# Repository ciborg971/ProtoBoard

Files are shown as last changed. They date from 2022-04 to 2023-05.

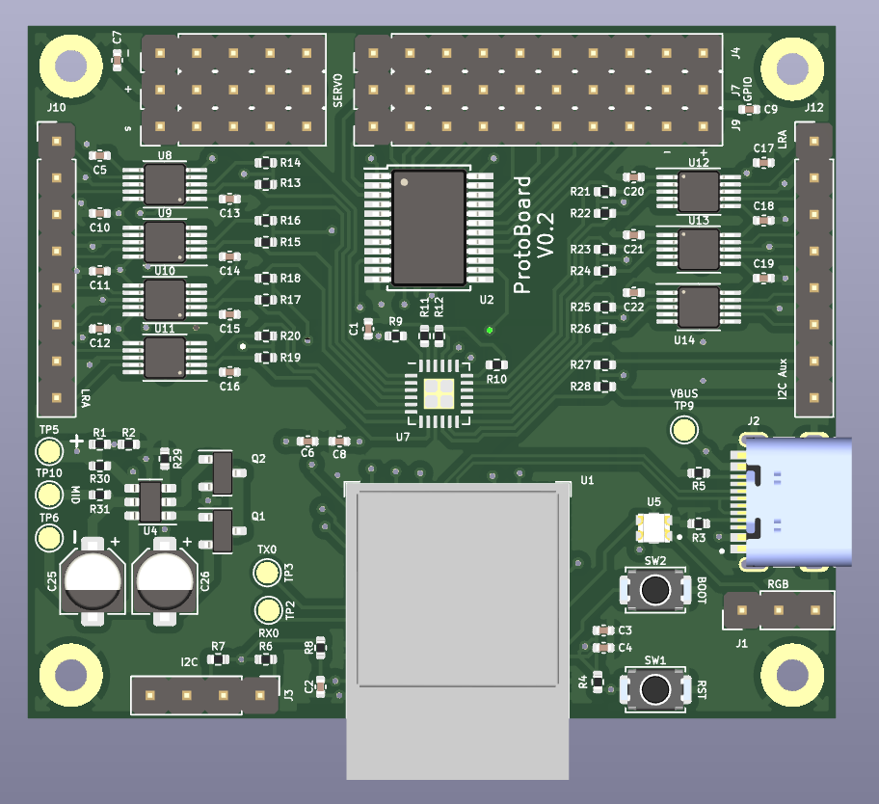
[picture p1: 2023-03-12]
media/3dTop.png

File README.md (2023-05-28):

# ProtoBoard V0.2

A small board (48 x 56 mm) for great gloves !

* Still a work in progress, current version does NOT work * 





# Features

## Pros :
- ESP32S3 dual core
- Small (48x56 mm)
- Power from 2S to 4S lipo (accept 6.5 volt up to 20 volt)
- Can use Wifi (doesnt use ADC2)
- 16 ADC input
- RGB Header
- 5V 5A for Servo for up to 5 Servo
- Support up to 7 LRA
- Battery protection (integrated BMS : overcharge, overdischarge and overcurrent protection)
- Battery level (via voltage divider)
- Cheap to build
- Use 2.54 mm header
- USB C for programming (The board CANNOT be powered via USB)

## Cons :
- Compoment on both side => more expensive to produce in small quantity in pcb fab (bottom side have easy to solder components)
- Doesnt charge the battery
- PCB is 4 layer (a bit more expensive than 2 layer PCB)

## Buy the PCB

*This design does NOT work right now, do NOT buy it unless you can debug it by yourself*
You can buy the board via PCBWay using the file ProtoBoard.kicad_pcb.zip and the BOM ProtoBoard.xlsx.

## TODO

- Add pinout

## Sponsors

This project is sponsored by PCBWay, thanks to them for their quality PCB + assembly !

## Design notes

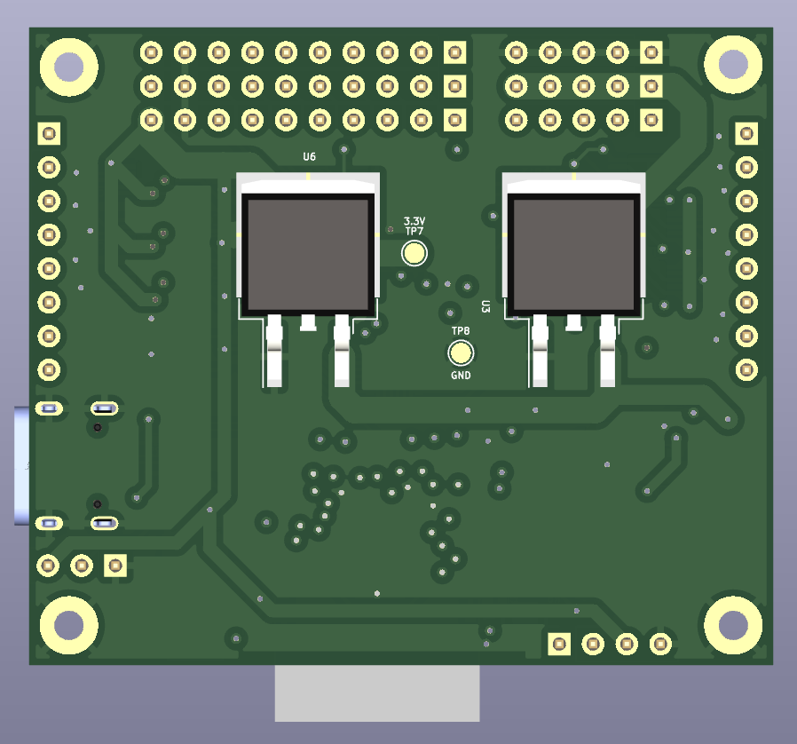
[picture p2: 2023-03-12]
media/3dBot.png

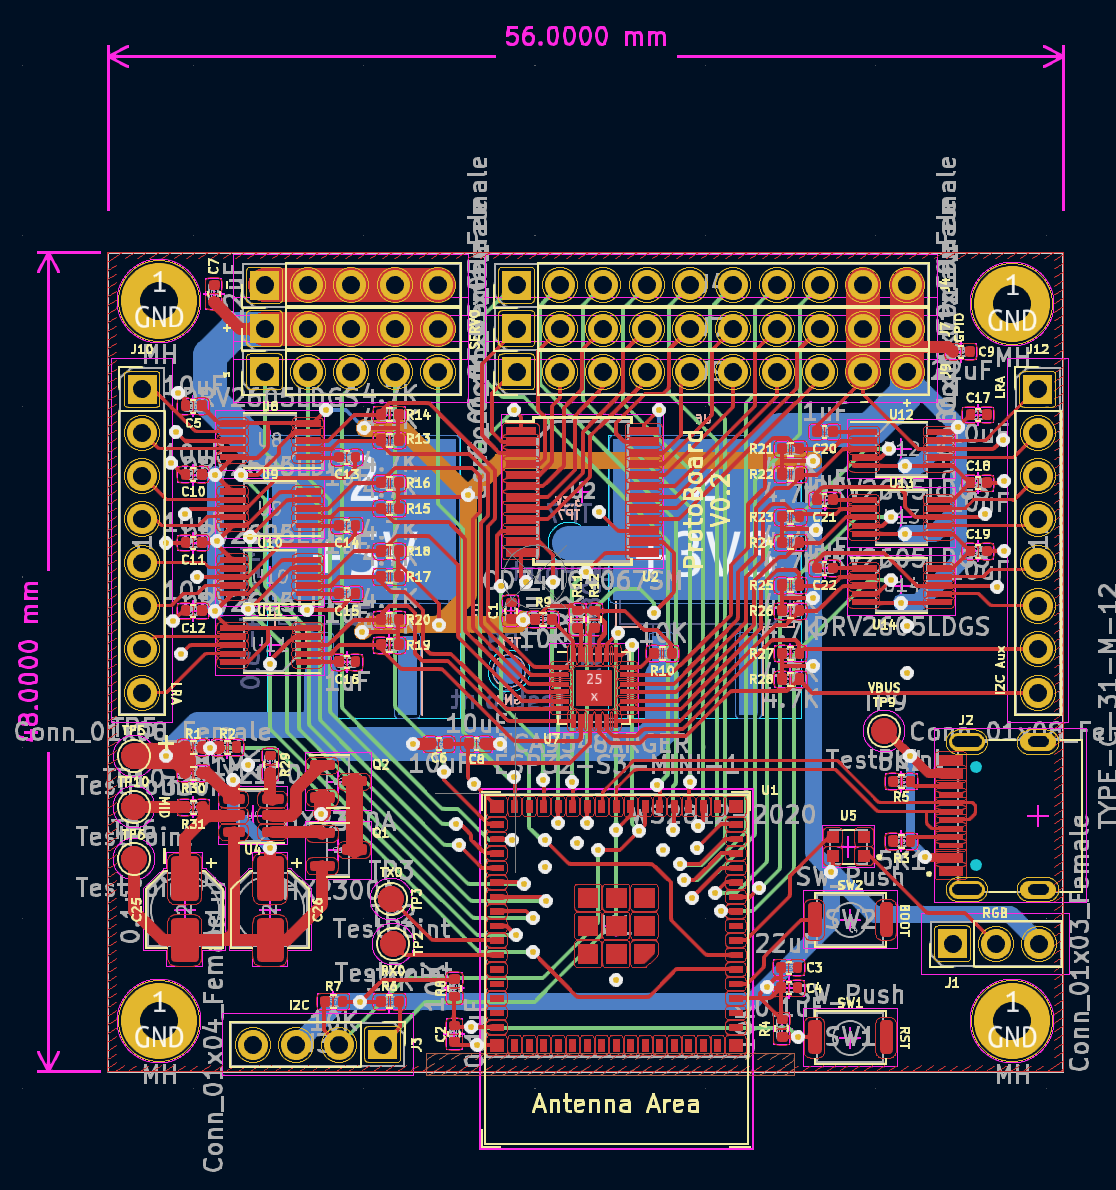
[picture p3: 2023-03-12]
media/Pcb.png

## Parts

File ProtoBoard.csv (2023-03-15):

Source: | C:\Users\termi\source\repos\ProtoBoard\ProtoBoard.kicad_sch
Date: | 15/03/2023 18:05:43
Tool: | Eeschema (6.0.11)
Generator: | C:\Program Files\KiCad\6.0\bin\scripting\plugins/bom_csv_grouped_by_value_with_fp.py
Component Count: | 96
Ref | Qnty | Value | Cmp name | Footprint | Description | Vendor
C1, C5, C6, C8, C10, C11, C12, C17, C18, C19, | 10 | 10uF | C | Capacitor_SMD:C_0402_1005Metric | Unpolarized capacitor
C2, C4, | 2 | 0.1uF | C | Capacitor_SMD:C_0402_1005Metric | Unpolarized capacitor
C3, C7, C9, | 3 | 22uF | C | Capacitor_SMD:C_0402_1005Metric | Unpolarized capacitor
C13, C14, C15, C16, C20, C21, C22, | 7 | 1uF | C | Capacitor_SMD:C_0402_1005Metric | Unpolarized capacitor
C25, C26, | 2 | 0.1uF | C_Polarized_Small | Capacitor_SMD:CP_Elec_4x5.4 | Polarized capacitor, small symbol
H1, H2, H3, H4, | 4 | MH | MountingHole_Pad | MountingHole:MountingHole_2.2mm_M2_Pad | Mounting Hole with connection
J1, | 1 | Conn_01x03_Female | Conn_01x03_Female | Connector_PinHeader_2.54mm:PinHeader_1x03_P2.54mm_Vertical | Generic connector, single row, 01x03, script generated (kicad-library-utils/schlib/autogen/connector/)
J2, | 1 | TYPE-C-31-M-12 | TYPE-C-31-M-12 | TYPE-C-31-M-12:HRO_TYPE-C-31-M-12
J3, | 1 | Conn_01x04_Female | Conn_01x04_Female | Connector_PinHeader_2.54mm:PinHeader_1x04_P2.54mm_Vertical | Generic connector, single row, 01x04, script generated (kicad-library-utils/schlib/autogen/connector/)
J4, J7, J9, | 3 | Conn_01x10_Female | Conn_01x10_Female | Connector_PinHeader_2.54mm:PinHeader_1x10_P2.54mm_Vertical | Generic connector, single row, 01x10, script generated (kicad-library-utils/schlib/autogen/connector/)
J5, J6, J8, | 3 | Conn_01x05_Female | Conn_01x05_Female | Connector_PinHeader_2.54mm:PinHeader_1x05_P2.54mm_Vertical | Generic connector, single row, 01x05, script generated (kicad-library-utils/schlib/autogen/connector/)
J10, J12, | 2 | Conn_01x08_Female | Conn_01x08_Female | Connector_PinHeader_2.54mm:PinHeader_1x08_P2.54mm_Vertical | Generic connector, single row, 01x08, script generated (kicad-library-utils/schlib/autogen/connector/)
Q1, Q2, | 2 | HX2300A | 2N7002E | Package_TO_SOT_SMD:SOT-23 | 0.24A Id, 60V Vds, N-Channel MOSFET, SOT-23
R1, | 1 | 5M | R | Resistor_SMD:R_0402_1005Metric | Resistor
R2, | 1 | 1M | R | Resistor_SMD:R_0402_1005Metric | Resistor
R3, R5, | 2 | 5K1 | R | Resistor_SMD:R_0402_1005Metric | Resistor
R4, R6, R7, R8, R9, R10, R11, R12, | 8 | 10K | R | Resistor_SMD:R_0402_1005Metric | Resistor
R13, R14, R15, R16, R17, R18, R19, R20, R21, R22, R23, R24, R25, R26, R27, R28, | 16 | 4.7K | R | Resistor_SMD:R_0402_1005Metric | Resistor
R29, | 1 | 2K | R | Resistor_SMD:R_0402_1005Metric | Resistor
R30, R31, | 2 | 330R | R | Resistor_SMD:R_0402_1005Metric | Resistor
SW1, SW2, | 2 | SW_Push | SW_Push | Button_Switch_SMD:SW_Push_SPST_NO_Alps_SKRK | Push button switch, generic, two pins
TP2, TP3, TP5, TP6, TP7, TP8, TP9, TP10, | 8 | TestPoint | TestPoint | TestPoint:TestPoint_Pad_D1.5mm | test point
U1, | 1 | ESP32-S3-MINI-1 | ESP32-S3-MINI-1 | Espressif:ESP32-S3-MINI-1 | Smallsized module supporting 2.4 GHz WiFi (802.11 b/g/n) and Bluetooth ® 5 (LE) Built around ESP32S3 series of SoCs, Xtensa ® dualcore 32bit LX7 microprocessor Flash up to 8 MB, optional 2 MB PSRAM in chip package 39 GPIOs, rich set of peripherals Onboard PCB antenna or external antenna connector
U2, | 1 | CD74HC4067SM | CD74HC4067SM | Package_SO:SSOP-24_5.3x8.2mm_P0.65mm | High-Speed CMOS Logic 16-Channel Analog Multiplexer/Demultiplexer, SSOP-24
U3, | 1 | LM1084-5.0 | LM1084-5.0 | Package_TO_SOT_SMD:TO-263-2 | 5A 27V Linear Regulator, Fixed Output 5.0V, TO-220/TO-263
U4, | 1 | HY2120 | HY2120 | Package_TO_SOT_SMD:SOT-23-6
U5, | 1 | WS2812-2020 | WS2812-2020 | WS2812-2020:LED_WS2812-2020
U6, | 1 | LM1084-3.3 | LM1084-3.3 | Package_TO_SOT_SMD:TO-263-2 | 5A 27V Linear Regulator, Fixed Output 3.3V, TO-220/TO-263
U7, | 1 | TCA9548ARGER | TCA9548ARGER | Package_DFN_QFN:Texas_RGE0024C_EP2.1x2.1mm | Low voltage 8-channel I2C switch with reset, QFN-24
U8, U9, U10, U11, U12, U13, U14, | 7 | DRV2605LDGS | DRV2605LDGS | Package_SO:VSSOP-10_3x3mm_P0.5mm | Haptic driver for LRAs and ERMs with effect library, 2-5.2V, VSSOP-10

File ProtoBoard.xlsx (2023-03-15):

Source: | ProtoBoard\ProtoBoard.kicad_sch
Component Count: | 77
Ref | Qnty | Value | Cmp name | Footprint | Description | Vendor | LCSC
C1, C5, C6, C8, C10, C11, C12, C17, C18, C19, | 10 | 10uF | C | Capacitor_SMD:C_0402_1005Metric | Unpolarized capacitor |  | C315248
C2, C4, | 2 | 0.1uF | C | Capacitor_SMD:C_0402_1005Metric | Unpolarized capacitor |  | C129131
C3, C7, C9, | 3 | 22uF | C | Capacitor_SMD:C_0402_1005Metric | Unpolarized capacitor |  | C415703
C13, C14, C15, C16, C20, C21, C22, | 7 | 1uF | C | Capacitor_SMD:C_0402_1005Metric | Unpolarized capacitor |  | C14445
C25, C26, | 2 | 0.1uF | C_Polarized_Small | Capacitor_SMD:CP_Elec_4x5.4 | Polarized capacitor, small symbol |  | C1525
J2, | 1 | TYPE-C-31-M-12 | TYPE-C-31-M-12 | TYPE-C-31-M-12:HRO_TYPE-C-31-M-12 |  |  | C165948
J5, J6, J8, | 3 | Conn_01x05_Female | Conn_01x05_Female | Connector_PinHeader_2.54mm:PinHeader_1x05_P2.54mm_Vertical | Generic connector, single row, 01x05, script generated (kicad-library-utils/schlib/autogen/connector/) |  | C492404
Q1, Q2, | 2 | HX2300A | 2N7002E | Package_TO_SOT_SMD:SOT-23 | 0.24A Id, 60V Vds, N-Channel MOSFET, SOT-23 |  | C296302
R1, | 1 | 5M | R | Resistor_SMD:R_0402_1005Metric | Resistor |  | C269650
R2, | 1 | 1M | R | Resistor_SMD:R_0402_1005Metric | Resistor |  | C138033
R3, R5, | 2 | 5K1 | R | Resistor_SMD:R_0402_1005Metric | Resistor |  | C25905
R4, R6, R7, R8, R9, R10, R11, R12, | 8 | 10K | R | Resistor_SMD:R_0402_1005Metric | Resistor |  | C60490
R13, R14, R15, R16, R17, R18, R19, R20, R21, R22, R23, R24, R25, R26, R27, R28, | 16 | 4.7K | R | Resistor_SMD:R_0402_1005Metric | Resistor |  | C105871
R29, | 1 | 2K | R | Resistor_SMD:R_0402_1005Metric | Resistor |  | C60488
R30, R31, | 2 | 330R | R | Resistor_SMD:R_0402_1005Metric | Resistor |  | C105875
SW1, SW2, | 2 | SW_Push | SW_Push | Button_Switch_SMD:SW_Push_SPST_NO_Alps_SKRK | Push button switch, generic, two pins |  | C115357
U1, | 1 | ESP32-S3-MINI-1 | ESP32-S3-MINI-1 | Espressif:ESP32-S3-MINI-1 | Smallsized module supporting 2.4 GHz WiFi (802.11 b/g/n) and Bluetooth ® 5 (LE) Built around ESP32S3 series of SoCs, Xtensa ® dualcore 32bit LX7 microprocessor Flash up to 8 MB, optional 2 MB PSRAM in chip package 39 GPIOs, rich set of peripherals Onboard PCB antenna or external antenna connector |  | C2913206
U2, | 1 | CD74HC4067SM | CD74HC4067SM | Package_SO:SSOP-24_5.3x8.2mm_P0.65mm | High-Speed CMOS Logic 16-Channel Analog Multiplexer/Demultiplexer, SSOP-24 |  | C98457
U3, | 1 | LM1084-5.0 | LM1084-5.0 | Package_TO_SOT_SMD:TO-263-2 | 5A 27V Linear Regulator, Fixed Output 5.0V, TO-220/TO-263 |  | C259973
U4, | 1 | HY2120 | HY2120-CB | Package_TO_SOT_SMD:SOT-23-6 |  |  | C116509
U5, | 1 | WS2812-2020 | WS2812B-2020 | WS2812-2020:LED_WS2812-2020 |  |  | C965555
U6, | 1 | LM1084-3.3 | LM1084-3.3 | Package_TO_SOT_SMD:TO-263-2 | 5A 27V Linear Regulator, Fixed Output 3.3V, TO-220/TO-263 |  | C259972
U7, | 1 | TCA9548ARGER | TCA9548ARGER | Package_DFN_QFN:Texas_RGE0024C_EP2.1x2.1mm | Low voltage 8-channel I2C switch with reset, QFN-24 |  | C555456
U8, U9, U10, U11, U12, U13, U14, | 7 | DRV2605LDGS | DRV2605LDGS | Package_SO:VSSOP-10_3x3mm_P0.5mm | Haptic driver for LRAs and ERMs with effect library, 2-5.2V, VSSOP-10 |  | C527464

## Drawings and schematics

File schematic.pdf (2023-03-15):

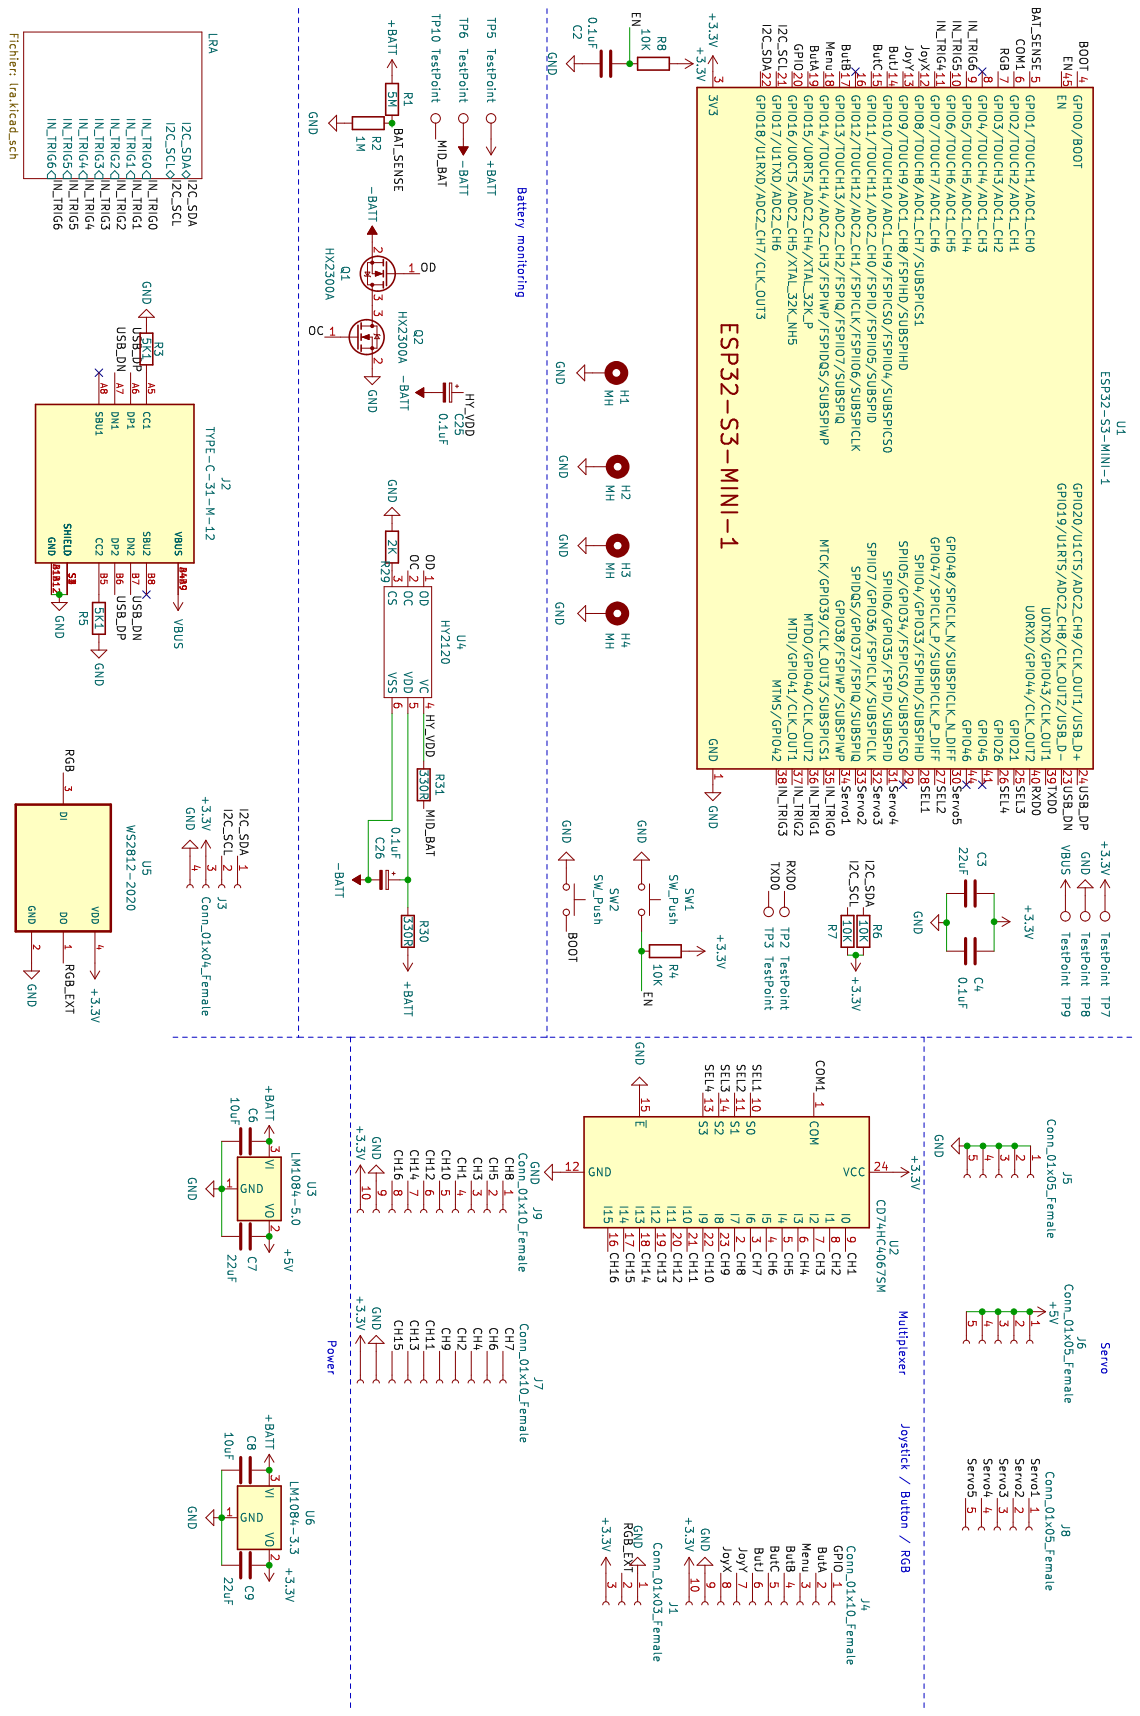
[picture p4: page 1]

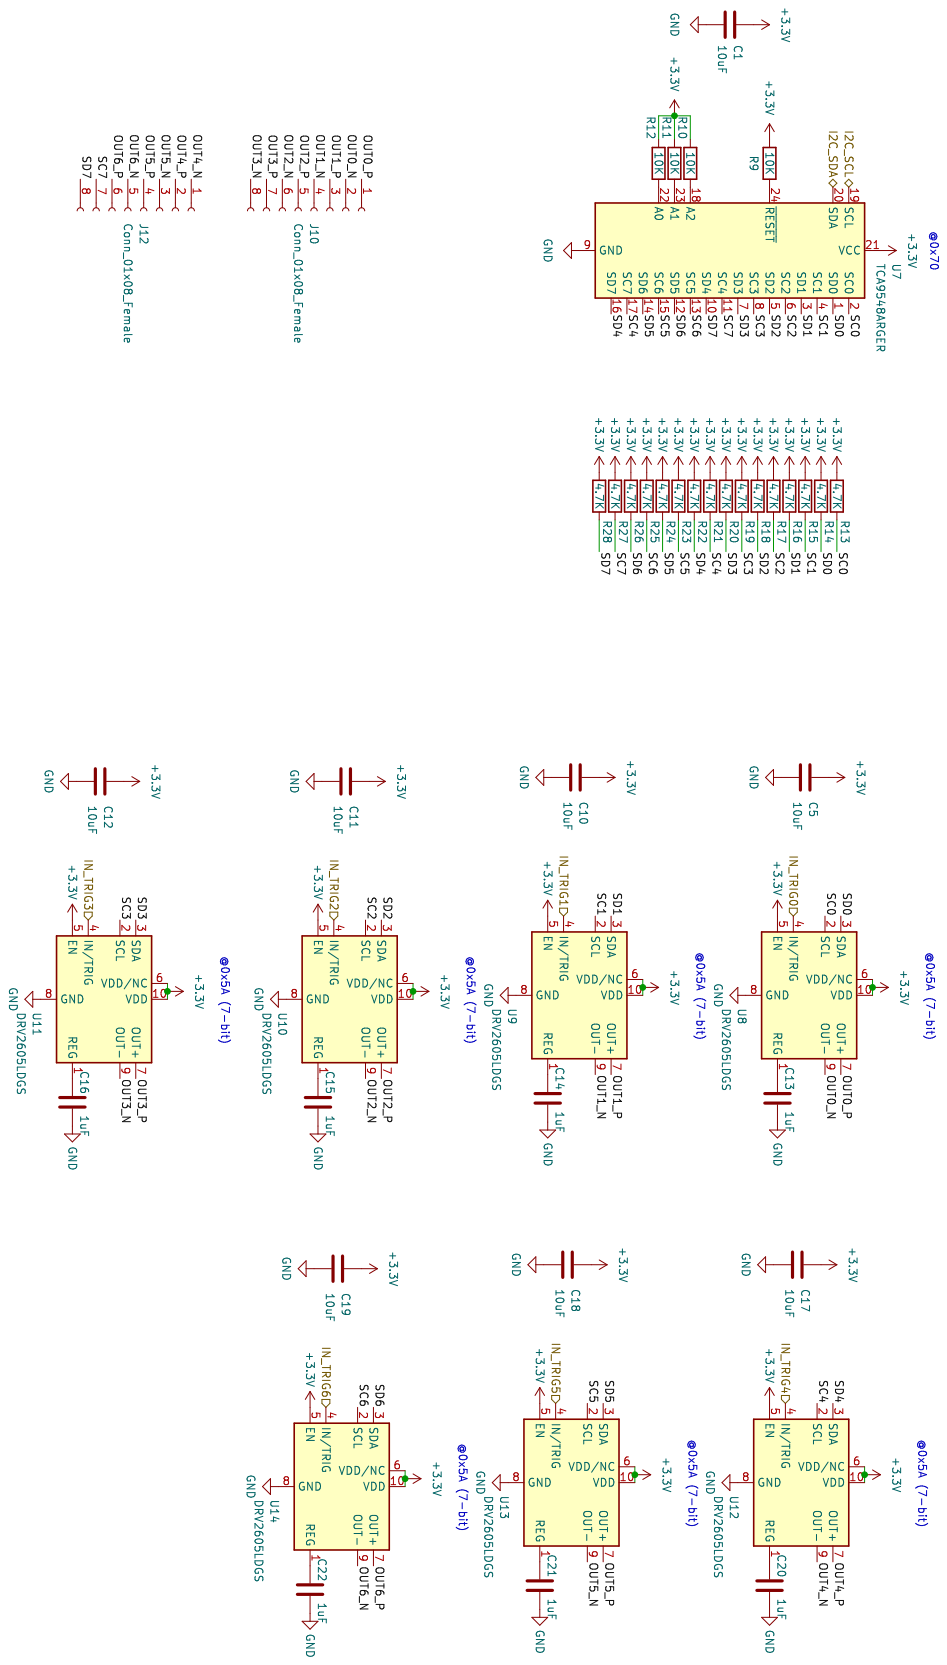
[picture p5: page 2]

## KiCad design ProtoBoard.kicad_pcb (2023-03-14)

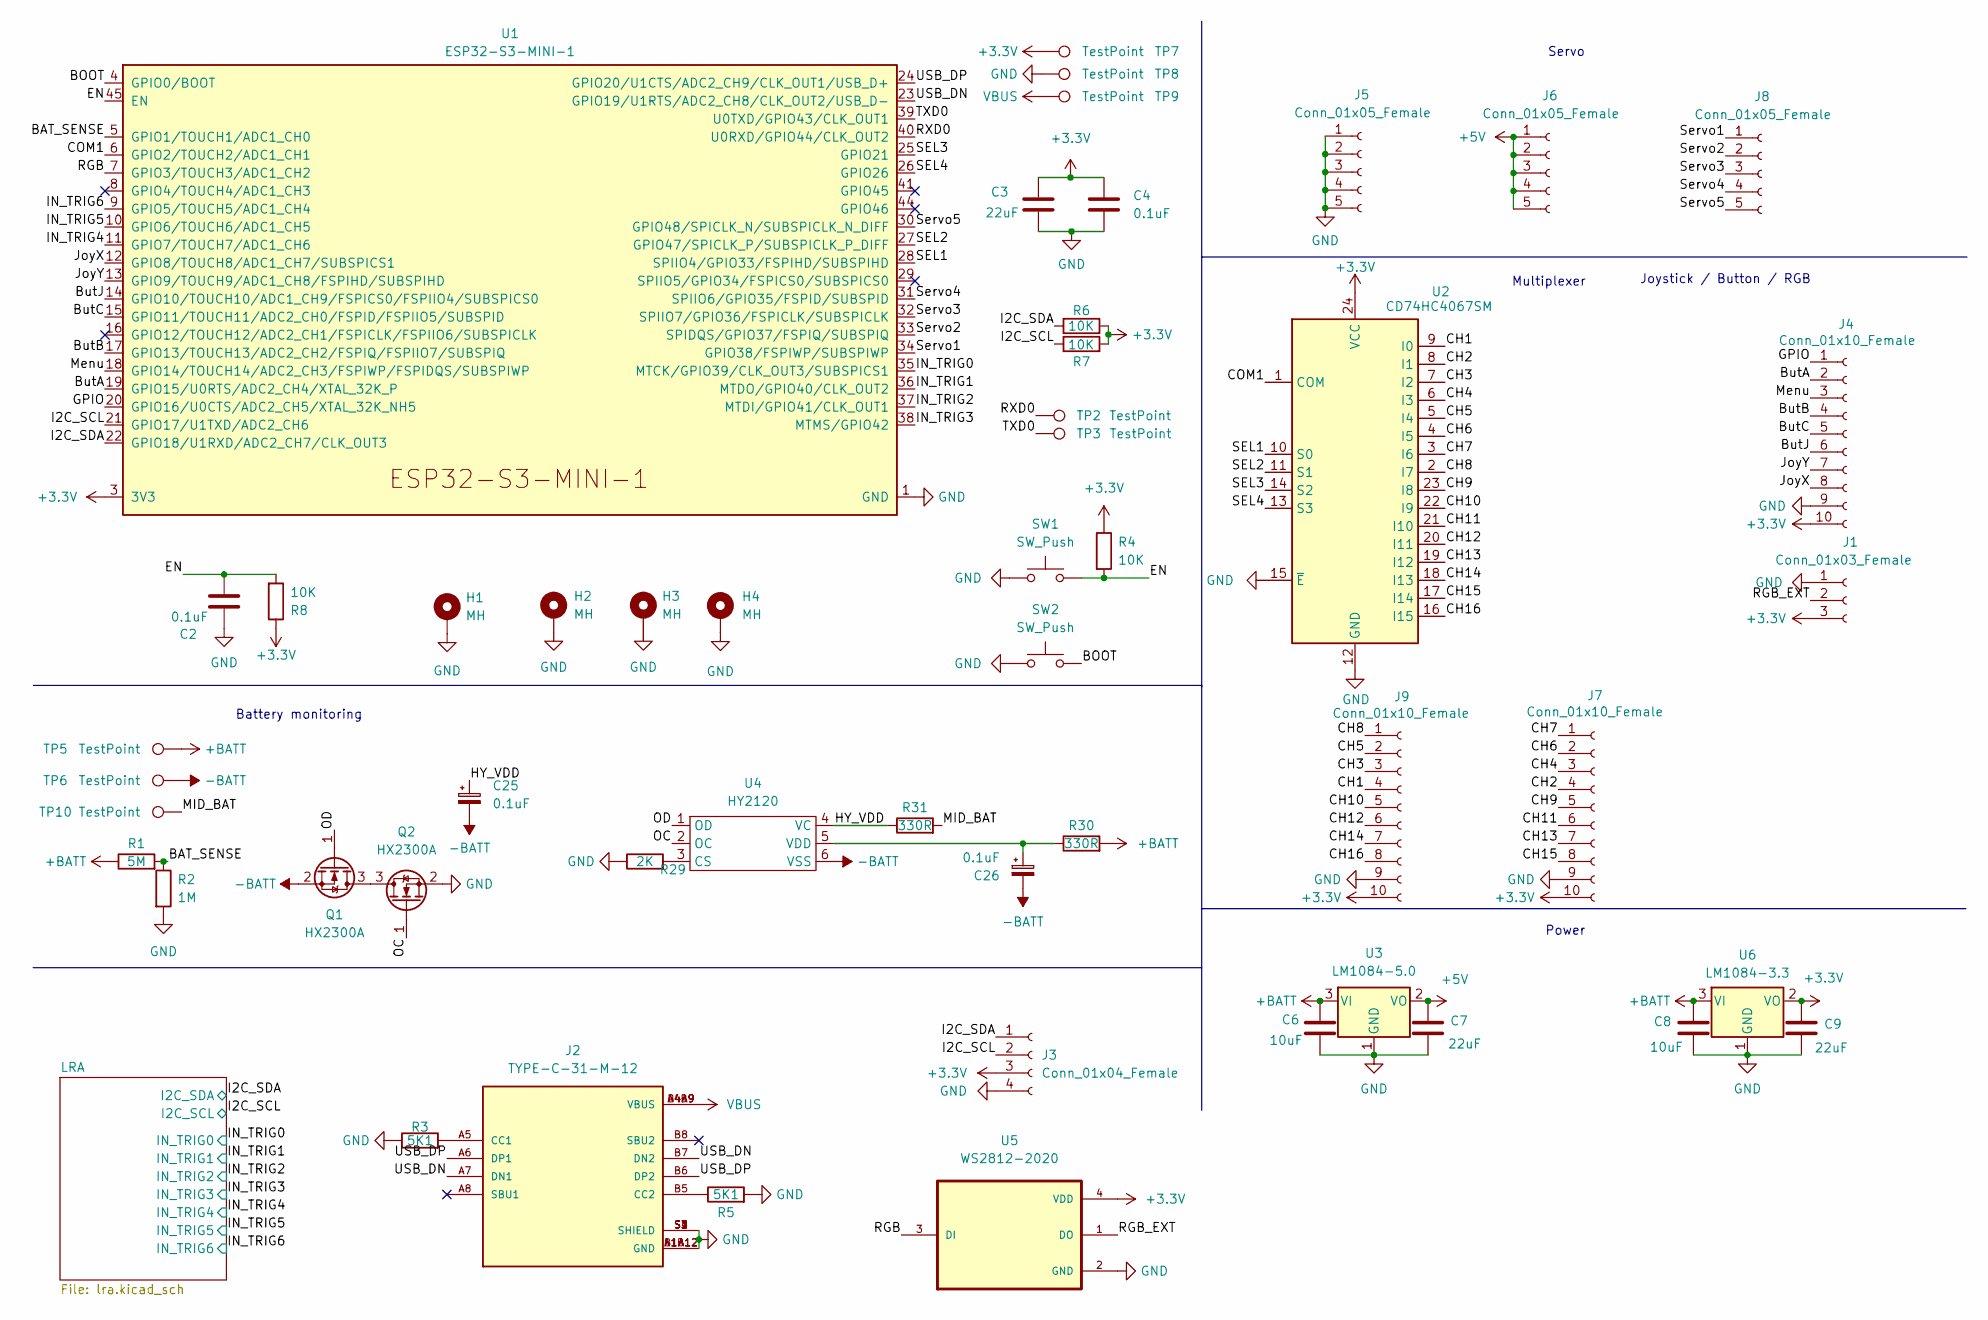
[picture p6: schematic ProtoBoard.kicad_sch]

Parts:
C2, C4: 0.1uF; C_0402_1005Metric
C3, C7, C9: 22uF; C_0402_1005Metric
C6, C8: 10uF; C_0402_1005Metric
C25, C26: 0.1uF; CP_Elec_4x5.4; LCSC C271438
H1, H2, H3, H4: MH; MountingHole_2.2mm_M2_Pad
J1: Conn_01x03_Female; PinHeader_1x03_P2.54mm_Vertical
J2: TYPE-C-31-M-12; HRO_TYPE-C-31-M-12; PARTREV A
J3: Conn_01x04_Female; PinHeader_1x04_P2.54mm_Vertical
J4, J7, J9: Conn_01x10_Female; PinHeader_1x10_P2.54mm_Vertical
J5, J6, J8: Conn_01x05_Female; PinHeader_1x05_P2.54mm_Vertical
Q1, Q2: HX2300A; SOT-23; LCSC C296302
R1: 5M; R_0402_1005Metric
R2: 1M; R_0402_1005Metric
R3, R5: 5K1; R_0402_1005Metric
R4, R6, R7, R8: 10K; R_0402_1005Metric
R29: 2K; R_0402_1005Metric
R30, R31: 330R; R_0402_1005Metric
SW1, SW2: SW_Push; SW_Push_SPST_NO_Alps_SKRK
TP2, TP3, TP5, TP6, TP7, TP8, TP9, TP10: TestPoint; TestPoint_Pad_D1.5mm
U1: ESP32-S3-MINI-1
U2: CD74HC4067SM; SSOP-24_5.3x8.2mm_P0.65mm
U3: LM1084-5.0; TO-263-2
U4: HY2120; SOT-23-6
U5: WS2812-2020; LED_WS2812-2020; LCSC C965555
U6: LM1084-3.3; TO-263-2

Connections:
+3V3: C3.1, C4.1, C9.1, J1.3, J3.3, J4.10, J7.10, J9.10, R4.1, R6.2, R7.2, R8.1, TP7.1, U1.3 (3V3), U2.24 (VCC), U5.4 (VDD), U6.2 (VO); also elsewhere on the board
+5V: C7.1, J6.1, J6.2, J6.3, J6.4, J6.5, U3.2 (VO)
+BATT: C6.1, C8.1, R1.1, R30.2, TP5.1, U3.3 (VI), U6.3 (VI)
-BATT: C25.2, C26.2, Q1.2 (S), TP6.1, U4.6 (VSS)
/BAT_SENSE: R1.2, R2.1, U1.5 (GPIO1/TOUCH1/ADC1_CH0)
/BOOT: SW2.2, U1.4 (GPIO0/BOOT)
/ButA: J4.2, U1.19 (GPIO15/U0RTS/ADC2_CH4/XTAL_32K_P)
/ButB: J4.4, U1.17 (GPIO13/TOUCH13/ADC2_CH2/FSPIQ/FSPIIO7/S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)
/ButC: J4.5, U1.15 (GPIO11/TOUCH11/ADC2_CH0/FSPID/FSPIIO5/S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)
/ButJ: J4.6, U1.14 (GPIO10/TOUCH10/ADC1_CH9/FSPICS0/FSPIIO4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)
/CH1: J9.4, U2.9 (I0)
/CH2: J7.4, U2.8 (I1)
/CH3: J9.3, U2.7 (I2)
/CH4: J7.3, U2.6 (I3)
/CH5: J9.2, U2.5 (I4)
/CH6: J7.2, U2.4 (I5)
/CH7: J7.1, U2.3 (I6)
/CH8: J9.1, U2.2 (I7)
/CH9: J7.5, U2.23 (I8)
/CH10: J9.5, U2.22 (I9)
/CH11: J7.6, U2.21 (I10)
/CH12: J9.6, U2.20 (I11)
/CH13: J7.7, U2.19 (I12)
/CH14: J9.7, U2.18 (I13)
/CH15: J7.8, U2.17 (I14)
/CH16: J9.8, U2.16 (I15)
/COM1: U1.6 (GPIO2/TOUCH2/ADC1_CH1), U2.1 (COM)
/EN: C2.2, R4.2, R8.2, SW1.2, U1.45 (EN)
/GPIO: J4.1, U1.20 (GPIO16/U0CTS/ADC2_CH5/XTAL_32K_NH5)
/HY_VDD: C25.1, R31.1, U4.4 (VC)
/I2C_SCL: J3.2, R7.1, U1.21 (GPIO17/U1TXD/ADC2_CH6); also elsewhere on the board
/I2C_SDA: J3.1, R6.1, U1.22 (GPIO18/U1RXD/ADC2_CH7/CLK_OUT3); also elsewhere on the board
/IN_TRIG0: U1.35 (MTCK/GPIO39/CLK_OUT3/SUBSPICS1); also elsewhere on the board
/IN_TRIG1: U1.36 (MTDO/GPIO40/CLK_OUT2); also elsewhere on the board
/IN_TRIG2: U1.37 (MTDI/GPIO41/CLK_OUT1); also elsewhere on the board
/IN_TRIG3: U1.38 (MTMS/GPIO42); also elsewhere on the board
/IN_TRIG4: U1.11 (GPIO7/TOUCH7/ADC1_CH6); also elsewhere on the board
/IN_TRIG5: U1.10 (GPIO6/TOUCH6/ADC1_CH5); also elsewhere on the board
/IN_TRIG6: U1.9 (GPIO5/TOUCH5/ADC1_CH4); also elsewhere on the board
/JoyX: J4.8, U1.12 (GPIO8/TOUCH8/ADC1_CH7/SUBSPICS1)
/JoyY: J4.7, U1.13 (GPIO9/TOUCH9/ADC1_CH8/FSPIHD/SUBSPIHD)
/MID_BAT: R31.2, TP10.1
/Menu: J4.3, U1.18 (GPIO14/TOUCH14/ADC2_CH3/FSPIWP/FSPIDQS/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)
/OC: Q2.1 (G), U4.2 (OC)
/OD: Q1.1 (G), U4.1 (OD)
/RGB: U1.7 (GPIO3/TOUCH3/ADC1_CH2), U5.3 (DI)
/RGB_EXT: J1.2, U5.1 (DO)
/RXD0: TP2.1, U1.40 (U0RXD/GPIO44/CLK_OUT2)
/SEL1: U1.28 (SPIIO4/GPIO33/FSPIHD/SUBSPIHD), U2.10 (S0)
/SEL2: U1.27 (GPIO47/SPICLK_P/SUBSPICLK_P_DIFF), U2.11 (S1)
/SEL3: U1.25 (GPIO21), U2.14 (S2)
/SEL4: U1.26 (GPIO26), U2.13 (S3)
/Servo1: J8.1, U1.34 (GPIO38/FSPIWP/SUBSPIWP)
/Servo2: J8.2, U1.33 (SPIDQS/GPIO37/FSPIQ/SUBSPIQ)
/Servo3: J8.3, U1.32 (SPIIO7/GPIO36/FSPICLK/SUBSPICLK)
/Servo4: J8.4, U1.31 (SPIIO6/GPIO35/FSPID/SUBSPID)
/Servo5: J8.5, U1.30 (GPIO48/SPICLK_N/SUBSPICLK_N_DIFF)
/TXD0: TP3.1, U1.39 (U0TXD/GPIO43/CLK_OUT1)
/USB_DN: J2.A7 (DN1), J2.B7 (DN2), U1.23 (GPIO19/U1RTS/ADC2_CH8/CLK_OUT2/USB_D-)
/USB_DP: J2.A6 (DP1), J2.B6 (DP2), U1.24 (GPIO20/U1CTS/ADC2_CH9/CLK_OUT1/USB_D+)
GND: C2.1, C3.2, C4.2, C6.2, C7.2, C8.2, C9.2, H1.1, H2.1, H3.1, H4.1, J1.1, J2.A1B12 (GND), J2.B1A12 (GND), J2.S1 (SHIELD), J2.S2 (SHIELD), J2.S3 (SHIELD), J2.S4 (SHIELD), J3.4, J4.9, J5.1, J5.2, J5.3, J5.4, J5.5, J7.9, J9.9, Q2.2 (S), R2.2, R3.1, R5.2, R29.1, SW1.1, SW2.1, TP8.1, U1.1 (GND), U1.2 (GND), U1.42 (GND), U1.43 (GND), U1.46 (GND), U1.47 (GND), U1.48 (GND), U1.49 (GND), U1.50 (GND), U1.51 (GND), U1.52 (GND), U1.53 (GND), U1.54 (GND), U1.55 (GND), U1.56 (GND), U1.57 (GND), U1.58 (GND), U1.59 (GND), U1.60 (GND), U1.61 (GND), U1.62 (GND), U1.63 (GND), U1.64 (GND), U1.65 (GND), U2.12 (GND), U2.15 (~E), U3.1 (GND), U5.2 (GND), U6.1 (GND); also elsewhere on the board
unnamed: C26.1, R30.1, U4.5 (VDD)
unnamed: J2.A5 (CC1), R3.2
unnamed: J2.B5 (CC2), R5.1
unnamed: Q1.3 (D), Q2.3 (D)
unnamed: R29.2, U4.3 (CS)
VBUS: J2.A4B9 (VBUS), J2.B4A9 (VBUS), TP9.1

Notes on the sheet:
Multiplexer
Battery monitoring
Power
Joystick / Button / RGB
Servo

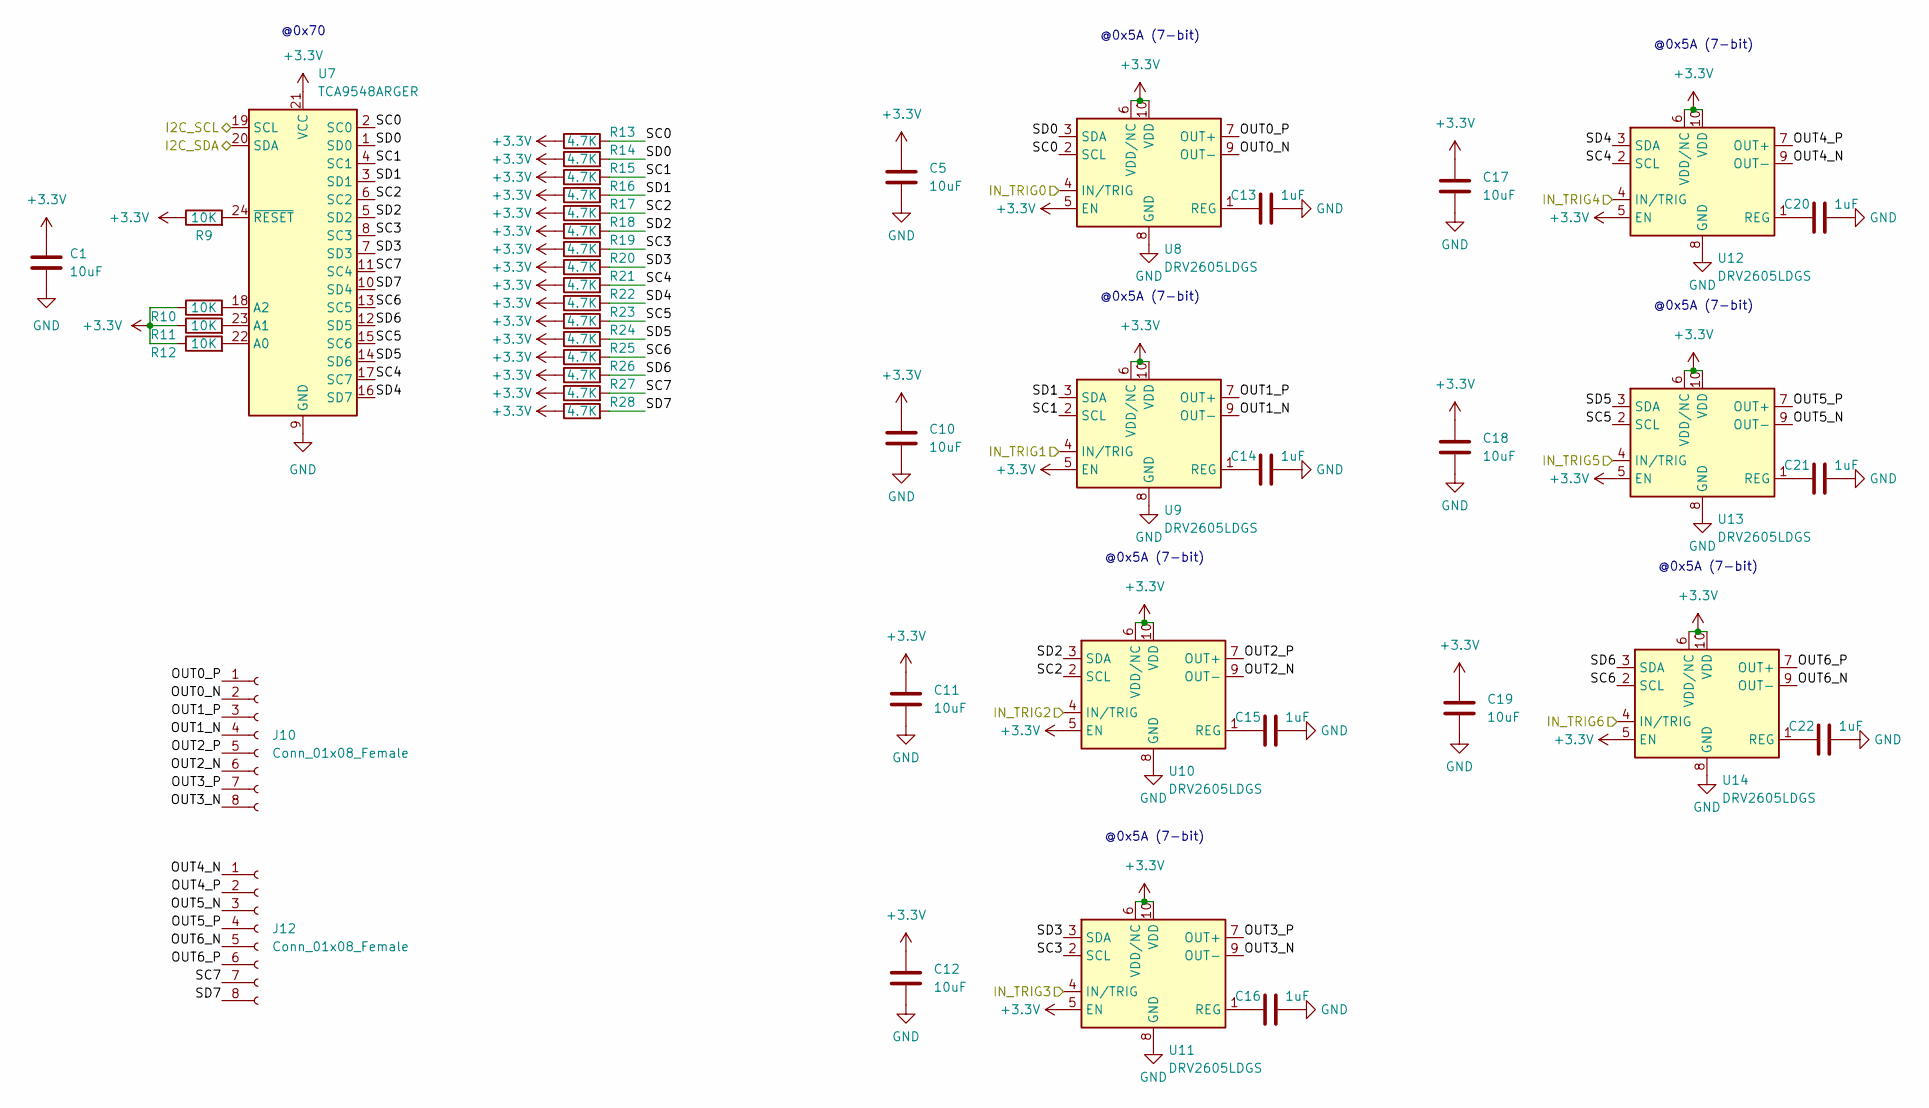
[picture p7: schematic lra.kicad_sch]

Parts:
C1, C5, C10, C11, C12, C17, C18, C19: 10uF; C_0402_1005Metric
C13, C14, C15, C16, C20, C21, C22: 1uF; C_0402_1005Metric
J10, J12: Conn_01x08_Female; PinHeader_1x08_P2.54mm_Vertical
R9, R10, R11, R12: 10K; R_0402_1005Metric
R13, R14, R15, R16, R17, R18, R19, R20, R21, R22, R23, R24, R25, R26, R27, R28: 4.7K; R_0402_1005Metric
U7: TCA9548ARGER; Texas_RGE0024C_EP2.1x2.1mm
U8, U9, U10, U11, U12, U13, U14: DRV2605LDGS; VSSOP-10_3x3mm_P0.5mm; LCSC C527464

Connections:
+3V3: C1.1, C5.1, C10.1, C11.1, C12.1, C17.1, C18.1, C19.1, R9.1, R10.1, R11.1, R12.1, R13.1, R14.1, R15.1, R16.1, R17.1, R18.1, R19.1, R20.1, R21.1, R22.1, R23.1, R24.1, R25.1, R26.1, R27.1, R28.1, U7.21 (VCC), U8.5 (EN), U8.6 (VDD/NC), U8.10 (VDD), U9.5 (EN), U9.6 (VDD/NC), U9.10 (VDD), U10.5 (EN), U10.6 (VDD/NC), U10.10 (VDD), U11.5 (EN), U11.6 (VDD/NC), U11.10 (VDD), U12.5 (EN), U12.6 (VDD/NC), U12.10 (VDD), U13.5 (EN), U13.6 (VDD/NC), U13.10 (VDD), U14.5 (EN), U14.6 (VDD/NC), U14.10 (VDD); also elsewhere on the board
/I2C_SCL: U7.19 (SCL); also elsewhere on the board
/I2C_SDA: U7.20 (SDA); also elsewhere on the board
/IN_TRIG0: U8.4 (IN/TRIG); also elsewhere on the board
/IN_TRIG1: U9.4 (IN/TRIG); also elsewhere on the board
/IN_TRIG2: U10.4 (IN/TRIG); also elsewhere on the board
/IN_TRIG3: U11.4 (IN/TRIG); also elsewhere on the board
/IN_TRIG4: U12.4 (IN/TRIG); also elsewhere on the board
/IN_TRIG5: U13.4 (IN/TRIG); also elsewhere on the board
/IN_TRIG6: U14.4 (IN/TRIG); also elsewhere on the board
/LRA/OUT0_N: J10.2, U8.9 (OUT-)
/LRA/OUT0_P: J10.1, U8.7 (OUT+)
/LRA/OUT1_N: J10.4, U9.9 (OUT-)
/LRA/OUT1_P: J10.3, U9.7 (OUT+)
/LRA/OUT2_N: J10.6, U10.9 (OUT-)
/LRA/OUT2_P: J10.5, U10.7 (OUT+)
/LRA/OUT3_N: J10.8, U11.9 (OUT-)
/LRA/OUT3_P: J10.7, U11.7 (OUT+)
/LRA/OUT4_N: J12.1, U12.9 (OUT-)
/LRA/OUT4_P: J12.2, U12.7 (OUT+)
/LRA/OUT5_N: J12.3, U13.9 (OUT-)
/LRA/OUT5_P: J12.4, U13.7 (OUT+)
/LRA/OUT6_N: J12.5, U14.9 (OUT-)
/LRA/OUT6_P: J12.6, U14.7 (OUT+)
/LRA/SC0: R13.2, U7.2 (SC0), U8.2 (SCL)
/LRA/SC1: R15.2, U7.4 (SC1), U9.2 (SCL)
/LRA/SC2: R17.2, U7.6 (SC2), U10.2 (SCL)
/LRA/SC3: R19.2, U7.8 (SC3), U11.2 (SCL)
/LRA/SC4: R21.2, U7.17 (SC7), U12.2 (SCL)
/LRA/SC5: R23.2, U7.15 (SC6), U13.2 (SCL)
/LRA/SC6: R25.2, U7.13 (SC5), U14.2 (SCL)
/LRA/SC7: J12.7, R27.2, U7.11 (SC4)
/LRA/SD0: R14.2, U7.1 (SD0), U8.3 (SDA)
/LRA/SD1: R16.2, U7.3 (SD1), U9.3 (SDA)
/LRA/SD2: R18.2, U7.5 (SD2), U10.3 (SDA)
/LRA/SD3: R20.2, U7.7 (SD3), U11.3 (SDA)
/LRA/SD4: R22.2, U7.16 (SD7), U12.3 (SDA)
/LRA/SD5: R24.2, U7.14 (SD6), U13.3 (SDA)
/LRA/SD6: R26.2, U7.12 (SD5), U14.3 (SDA)
/LRA/SD7: J12.8, R28.2, U7.10 (SD4)
GND: C1.2, C5.2, C10.2, C11.2, C12.2, C13.2, C14.2, C15.2, C16.2, C17.2, C18.2, C19.2, C20.2, C21.2, C22.2, U7.9 (GND), U8.8 (GND), U9.8 (GND), U10.8 (GND), U11.8 (GND), U12.8 (GND), U13.8 (GND), U14.8 (GND); also elsewhere on the board
unnamed: C13.1, U8.1 (REG)
unnamed: C14.1, U9.1 (REG)
unnamed: C15.1, U10.1 (REG)
unnamed: C16.1, U11.1 (REG)
unnamed: C20.1, U12.1 (REG)
unnamed: C21.1, U13.1 (REG)
unnamed: C22.1, U14.1 (REG)
unnamed: R9.2, U7.24 (~RESET)
unnamed: R10.2, U7.18 (A2)
unnamed: R11.2, U7.23 (A1)
unnamed: R12.2, U7.22 (A0)

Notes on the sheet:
@0x5A (7-bit)
@0x70

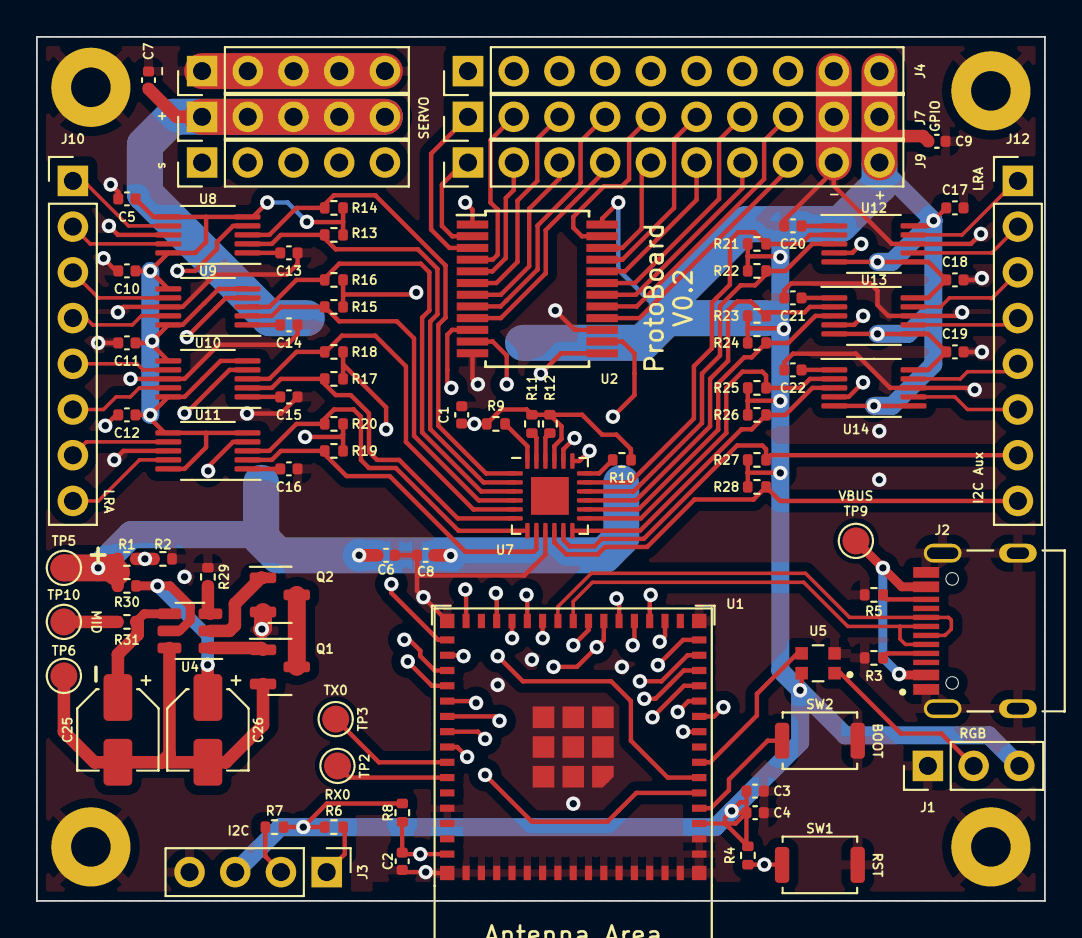
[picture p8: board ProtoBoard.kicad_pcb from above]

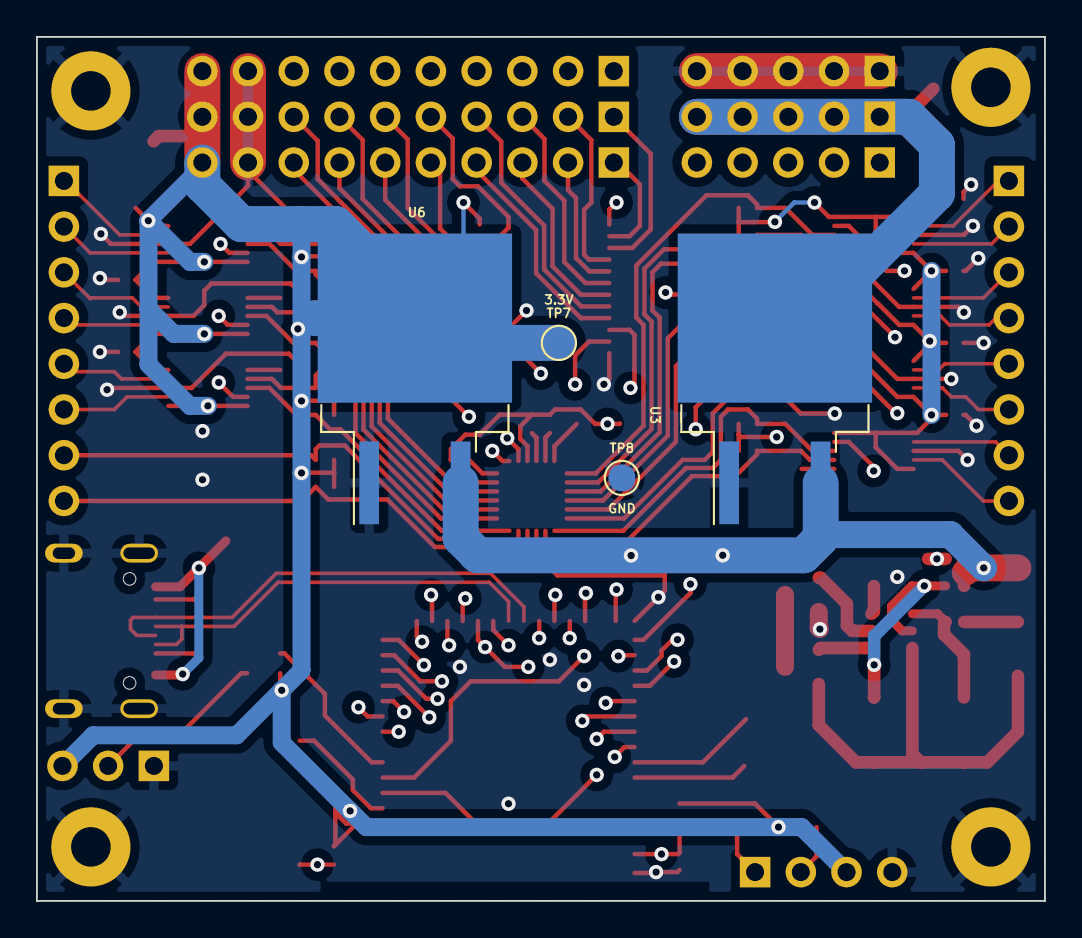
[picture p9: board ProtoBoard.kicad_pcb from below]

Board: 4 copper layers, 56.0 x 48.0 mm, 96 parts (4 on the bottom side), 108 nets.

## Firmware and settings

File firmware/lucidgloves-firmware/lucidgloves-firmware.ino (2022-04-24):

#include "Config.h"

#include "HardwareConfig.hpp"

#include "ICommunication.hpp"
#if COMMUNICATION == COMM_SERIAL
  #include "SerialCommunication.hpp"
#elif COMMUNICATION == COMM_BTSERIAL
  #include "SerialBTCommunication.hpp"
#endif

#include "AdcMux.hpp"

#define ALWAYS_CALIBRATING CALIBRATION_LOOPS == -1

ICommunication* comm;
int calibration_count = 0;

// These are composite lists of the hardware defined in the header above.
EncodedInput* inputs[MAX_INPUT_COUNT];
DecodedOuput* outputs[MAX_OUTPUT_COUNT];
Calibrated* calibrators[MAX_CALIBRATED_COUNT];

char* encoded_output_string;
size_t input_count;
size_t output_count;
size_t calibrated_count;

// Common pattern for registering inputs and outputs
#define register(source, destination, new_count, existing) \
do {                                                       \
  for (size_t i = 0; i < new_count; existing++, i++) {     \
    destination[existing] = source[i];                     \
  }                                                        \
} while(false)

void setup() {
  #if COMMUNICATION == COMM_SERIAL
    comm = new SerialCommunication();
  #elif COMMUNICATION == COMM_BTSERIAL
    comm = new BTSerialCommunication();
  #endif

  comm->start();

  // Register the inputs.
  input_count = 0;
  register(buttons, inputs, BUTTON_COUNT, input_count);
  register(fingers, inputs, FINGER_COUNT, input_count);
  register(joysticks, inputs, JOYSTICK_COUNT, input_count);
  register(gestures, inputs, GESTURE_COUNT, input_count);

  // Register the calibrated inputs
  calibrated_count = 0;
  register(fingers, calibrators, FINGER_COUNT, calibrated_count);

  // Register the outputs.
  output_count = 0;
  register(force_feedbacks, outputs, FORCE_FEEDBACK_COUNT, output_count);
  register(haptics, outputs, HAPTIC_COUNT, output_count);

  // Figure out needed size for the output string.
  int string_size = 0;
  for(size_t i = 0; i < input_count; i++) {
    string_size += inputs[i]->getEncodedSize();
  }

  // Add 1 new line and 1 for the null terminator.
  encoded_output_string = new char[string_size + 1 + 1];

  // Setup all the inputs.
  for (size_t i = 0; i < input_count; i++) {
    inputs[i]->setupInput();
  }

  // Setup all the outputs.
  for (size_t i = 0; i < output_count; i++) {
    outputs[i]->setupOutput();
  }

  // Setup the LED.
  led.setup();

  // Setup Multiplexer
  SetupAdcMux();

  if (ALWAYS_CALIBRATING) {
    for (size_t i = 0; i < calibrated_count; i++) {
      calibrators[i]->enableCalibration();
    }
  }
}

void loop() {
  if (!comm->isOpen()){
    // Connection to Driver not ready, blink the LED to indicate no connection.
    led.setState(LED::State::BLINK_STEADY);
  } else {
    // All is good, LED on to indicate a good connection.
    led.setState(LED::State::ON);
  }

  // Notify the calibrators to turn on.
  if (calibration_button.isPressed()) {
    calibration_count = 0;
    for (size_t i = 0; i < calibrated_count; i++) {
      calibrators[i]->resetCalibration();
      calibrators[i]->enableCalibration();
    }
  }

  if (calibration_count < CALIBRATION_LOOPS || ALWAYS_CALIBRATING) {
    // Keep calibrating for one at least one more loop.
    calibration_count++;
  } else {
    // Calibration is done, notify the calibrators
    for (size_t i = 0; i < calibrated_count; i++) {
      calibrators[i]->disableCalibration();
    }
  }

  // Update all the inputs
  for (int i = 0; i < input_count; i++) {
    inputs[i]->readInput();
  }

  // Encode all of the outputs to a single string.
  encodeAll(encoded_output_string, inputs, input_count);

  // Send the string to the communication handler.
  comm->output(encoded_output_string);

  char received_bytes[100];
  if (comm->hasData() && comm->readData(received_bytes, 100)) {
    for (size_t i = 0; i < output_count; i++) {
      // Decode the update and write it to the output.
      outputs[i]->decodeToOuput(received_bytes);
    }
  }

  // Allow all the outputs to update their state.
  for (size_t i = 0; i < output_count; i++) {
    outputs[i]->updateOutput();
  }

  delay(LOOP_TIME);
}

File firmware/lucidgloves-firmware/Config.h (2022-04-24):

/*
 * LucidGloves Firmware Version 5
 * Author: Lucas_VRTech - LucidVR
 *         John Thomas  - Exia
 * lucidvrtech.com
 * github.com/JohnRThomas/FlexiaGloves/
 */

// This is the main configuration file. Tweak settings here to fit your hardware.

// Which communication protocol to use
#define COMM_SERIAL 0
#define COMM_BTSERIAL 1
#define COMMUNICATION COMM_BTSERIAL

// Serial over USB
#define SERIAL_BAUD_RATE 115200

// Serial over Bluetooth
#define BTSERIAL_DEVICE_NAME "lucidgloves-left"

// Button Settings
// If a button registers as pressed when not and vice versa (eg. using normally-closed switches),
// you can invert their behaviour here by setting their line to true.
// If unsure, set to false
#define INVERT_A        false
#define INVERT_B        false
#define INVERT_JOY      false // Does nothing if joystick is not enabled
#define INVERT_MENU     false
#define INVERT_CALIB    false
#define INVERT_TRIGGER  false // Does nothing if gesture is enabled
#define INVERT_GRAB     false // Does nothing if gesture is enabled
#define INVERT_PINCH    false // Does nothing if gesture is enabled

// Joystick configuration
#define ENABLE_JOYSTICK  true // make false if not using the joystick
#define INVERT_JOY_X     false
#define INVERT_JOY_Y     false
#define JOYSTICK_DEADZONE 0.1 //deadzone in the joystick to prevent drift. Value out of 1.0.

// Finger settings
#define ENABLE_THUMB   true  // If for some reason you don't want to track the thumb
#define ENABLE_SPLAY   true // Track the side to side motion of fingers
#define INVERT_FLEXION false
#define INVERT_SPLAY   false

// Gesture enables, make false to use button override
#define TRIGGER_GESTURE true
#define GRAB_GESTURE    true
#define PINCH_GESTURE   (true && ENABLE_THUMB) // Cannot be enabled if there is no thumb

// Force Feedback and haptic settings
// Force feedback allows you to feel the solid objects you hold
// Haptics provide vibration.
#define ENABLE_FORCE_FEEDBACK true
#define ENABLE_HAPTICS        true

#define FORCE_FEEDBACK_FINGER_SCALING  false // Experimental: Determine servo range of motion based on calibration data.
#define FORCE_FEEDBACK_SMOOTH_STEPPING false // Experimental: Use servo microsecond pulses instead of degrees.

#define FORCE_FEEDBACK_STYLE_SERVO       0
#define FORCE_FEEDBACK_STYLE_CLAMP       1
#define FORCE_FEEDBACK_STYLE_SERVO_CLAMP 2
#define FORCE_FEEDBACK_STYLE             FORCE_FEEDBACK_STYLE_SERVO

#define FORCE_FEEDBACK_CLAMP_UNLOCK       LOW
#define FORCE_FEEDBACK_CLAMP_LOCK         HIGH
#define FORCE_FEEDBACK_SERVO_CLAMP_UNLOCK 0
#define FORCE_FEEDBACK_SERVO_CLAMP_LOCK   20

#define FORCE_FEEDBACK_MIN      0 // Value of 0 means no limit.
#define FORCE_FEEDBACK_MAX   1000 // Value of 1000 means maximum limit.
#define FORCE_FEEDBACK_RELEASE 50 // To prevent hardware damage, value passed the limit for when to release FFB. (Set to FORCE_FEEDBACK_MAX to disable)

// Counts of objects in the system used for looping
// Inputs
#define GESTURE_COUNT        (TRIGGER_GESTURE + GRAB_GESTURE + PINCH_GESTURE)
#define FINGER_COUNT         (ENABLE_THUMB ? 5 : 4)
#define JOYSTICK_COUNT       (ENABLE_JOYSTICK ? 2 : 0)
#define BUTTON_COUNT         (4 + ENABLE_JOYSTICK + !TRIGGER_GESTURE + !GRAB_GESTURE + !PINCH_GESTURE)
// Ouputs
#define HAPTIC_COUNT         (ENABLE_HAPTICS ? 1 : 0)
#define FORCE_FEEDBACK_COUNT (ENABLE_FORCE_FEEDBACK ? FINGER_COUNT : 0)
// Used for array allocations. These may need to be increased if more inputs are added.
#define MAX_INPUT_COUNT      32
#define MAX_CALIBRATED_COUNT 8
#define MAX_OUTPUT_COUNT     11

//PINS CONFIGURATION
//(This configuration is for ESP32 DOIT V1 so make sure to change if you're on another board)
#define PIN_PINKY           48
#define PIN_RING            49
#define PIN_MIDDLE          50
#define PIN_INDEX           51
#define PIN_THUMB           52
#define PIN_JOY_X           64
#define PIN_JOY_Y           65
#define PIN_JOY_BTN         66
#define PIN_A_BTN           70
#define PIN_B_BTN           68
#define PIN_MENU_BTN        69
#define PIN_TRIG_BTN        12 //unused if gesture set
#define PIN_GRAB_BTN        13 //unused if gesture set
#define PIN_PNCH_BTN        23 //unused if gesture set
#define PIN_CALIB           67 //button for recalibration
#define PIN_LED             23 // WS2812
#define PIN_PINKY_FFB       27 //used for force feedback
#define PIN_RING_FFB        14 //^
#define PIN_MIDDLE_FFB      12 //^
#define PIN_INDEX_FFB       13 //^
#define PIN_THUMB_FFB       15 //^
#define PIN_HAPTIC          18
#define PIN_PINKY_SPLAY     59
#define PIN_RING_SPLAY      60
#define PIN_MIDDLE_SPLAY    61
#define PIN_INDEX_SPLAY     62
#define PIN_THUMB_SPLAY     63
#define PIN_BAT             71
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

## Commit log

2022-04-09 schematic + rooted board
    TODO :
    - Check I2C address
    - Capacitor value for esp32
    - Part sourcing
    - Silkscreen
    [ProtoBoard.dsn, ProtoBoard.kicad_pcb, ProtoBoard.kicad_sch]
2022-04-10 add shunt resistor and set i2c addresses
    [ProtoBoard.kicad_pcb, ProtoBoard.kicad_sch]
2022-04-10 add schematic export
2022-04-19 smaller (but more expensive) version board
    [ProtoBoard.dsn, ProtoBoard.kicad_pcb, ProtoBoard.kicad_sch]
2022-04-21 Board cleaning progress
    [ProtoBoard.kicad_pcb, ProtoBoard.step]
2022-04-21 More pcb cleaning
    [ProtoBoard.kicad_pcb, ProtoBoard.kicad_sch]
2022-04-21 Remove diode
    [ProtoBoard.kicad_pcb, ProtoBoard.kicad_sch]
2022-04-21 Production file + 3D model
    [ProtoBoard-B_Cu.gbr, ProtoBoard-B_Mask.gbr, ProtoBoard-B_Paste.gbr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]
2022-04-24 Implemented mux support for button / finger / joystick + rgb led support
2022-04-24 documentation add buying pcb and started updating bom links
2023-03-05 Add bms + switch to esp32s3 + USB C + 8 LRA driver
    [ProtoBoard.kicad_pcb, ProtoBoard.kicad_sch, lra.kicad_sch]
2023-03-05 Routing WIP
    [ProtoBoard.kicad_pcb, ProtoBoard.kicad_sch]
2023-03-12 Routing done, silkscreen cleaning, update README, remove old files
    [ProtoBoard-B_Cu.gbr, ProtoBoard-B_Mask.gbr, ProtoBoard-B_Paste.gbr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]
2023-03-14 Fix bms + a bit clearer schematic
    [ProtoBoard.kicad_pcb, ProtoBoard.kicad_sch, lra.kicad_sch]
2023-03-14 Clearing schematic a bit more
    [ProtoBoard.kicad_sch]
2023-03-15 Small PCB layout modification, export schematic.pdf, BOM and production files for PCBWay
    [ProtoBoard-B_Cu.gbl, ProtoBoard-B_Mask.gbs, ProtoBoard-B_Paste.gbp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]
